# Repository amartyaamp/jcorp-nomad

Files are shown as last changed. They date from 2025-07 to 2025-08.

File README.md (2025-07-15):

# <div align="center">Jcorp Nomad</div>

<div align="center">
  Jcorp Nomad Offline Media Server
</div>

<p align="center"><b>A portable, offline media server powered by the ESP32-S3 in a thumbdrive form factor.</b><br>
Stream movies, music, books, and shows anywhere — no internet required.</p>

<p align="center">
  
  
  
</p>

---

## What is Nomad

Jcorp Nomad is an open-source offline media server built for travel, remote work, classrooms, camping, and more. It runs entirely on an ESP32-S3 dev board, creates a local Wi-Fi hotspot, and serves media through a browser-accessible interface. It does not require internet access and works similarly to in-flight entertainment systems. It also allows multiple users watching seperate media streams at the same time. 

This project is designed to be compact, simple, and easily modifiable. It includes optional 3D-printable hardware and a fully open source firmware and web interface.

---

## Project Inspiration
This project was inspired by my experience running a Jellyfin server at home. I love having full control over my media library, and Jellyfin gave me everything I wanted > streaming movies, shows, books, and music, all from my own hardware. Naturally, I started looking for ways to take that experience on the go.

My first thought was to build a portable server, but I quickly ran into some major hurdles:

- Power-hungry hardware — Even low-power x86 boxes needed a hefty battery setup to stay running for long trips.

- High cost — SBCs like the Raspberry Pi 4, plus power banks, USB storage, and screen interfaces added up quickly.

- Heat and reliability — Trying to cram a full stack of services into a compact case often led to thermal issues and instability when running software meant for server hardware.

That’s when I pivoted.

Instead of replicating a full home media server, I focused on delivering the core experience:

- Offline access

- Local Wi-Fi hotspot

- Simple media browsing and playback

- Support for multiple users

The ESP32-S3 offered just enough performance to handle all of that - with a fraction of the power draw and cost.
The result is Nomad: a minimalist, reliable, and low-cost media server that delivers the essential features of a home streaming setup in a smaller than pocket sized format.

Is it fancy? No.
Does it work? Absolutely.
And it’s open-source, so anyone can expand, improve, and adapt it for their own needs.

---

## Features

- Creates a local Wi-Fi hotspot with captive portal  
- Serves HTML media interface to any connected device  
- Streams content directly from a FAT32-formatted microSD card  
- Supports simultaneous connections (tested with up to 4 video streams)  
- No app or internet connection required  
- Open source firmware and UI  
- Customizable web interface / Features

---

## Hardware Requirements

**Disclaimer:**  
The following links are Amazon affiliate links. Purchasing through these links supports this project at no additional cost to you. Thank you for your support!

- **Waveshare ESP32-S3 Dev Board (1.47" LCD version)**  
  [https://amzn.to/4ktB6oT](https://amzn.to/4ktB6oT)

  [Backup, the other one's shiping is like 2 weeks now](https://amzn.to/4kGp7UT)

- **FAT32-formatted microSD card (16 GB minimum recommended, 64 GB preferred)**  
  [https://amzn.to/44tM1c4](https://amzn.to/44tM1c4)

- **USB power source** (e.g., battery bank or computer)

- **Optional:** 3D-printed enclosure (STL files included in the repository)

---

## Software Requirements

- Arduino IDE or PlatformIO (to flash firmware)
- Python 3.x (to run `media.py`)
- SquareLine Studio (optional, for screen UI editing)

All software used is free and available on Windows, macOS, and Linux.

---

## Quick Start

1. Flash the ESP32-S3 with the firmware in the `/firmware/` directory.
2. Format your SD card as **FAT32** and copy the web files from `/SD_Card_Template/`.
3. Place your media files into the appropriate folders (see structure below).
4. ~~Run `media.py` to generate `media.json` automatically.~~ Updated: Media.py is still there, but you dont need to run it, file will be generated on boot automaticaly!
5. Insert the SD card and power the device.
6. Connect to the Wi-Fi network named `Jcorp_Nomad`.
7. Your browser will be redirected to the offline media interface.

---

## Folder Structure (on SD Card)

```
/Movies/
    Interstellar.mp4
    Interstellar.jpg
/Shows/
    The Office/
        S01E01 - Pilot.mp4
        S01E02 - Diversity Day.mp4
    The Office.jpg
/Books/
    The Martian.pdf
    The Martian.jpg
/Music/
    track01.mp3

index.html
appleindex.html
menu.html
movies.html
shows.html
books.html
music.html
media.py
media.json
placeholder.jpg
Logo.png
favicon.ico
```
---

## Supported Formats

- Video: `.mp4`
- Audio: `.mp3`
- Books: `.pdf`
- Images: `.jpg` (used for covers and folder images only)

Ensure all images and media files use matching names for proper display.

---

## Customization

- Wi-Fi name and password can be changed in `firmware/Nomad.ino`
- Branding (logo, favicon) can be replaced in `/SD_Card_Template/`
- Sections (Movies, Music, etc.) can be removed from `menu.html`
- Web interface can be edited using any text editor
- The screen UI can be edited with SquareLine Studio (the free version is fine) 

---

## What's Included

- `/firmware/` – Arduino firmware for ESP32-S3
- `/SD_Card_Template/` – Web UI, HTML files, and `media.py`
- `/case/` – STL files for optional 3D-printed enclosure
- `/docs/` – Logos, screenshots, and design files

---

## Troubleshooting

Common issues and their solutions are detailed in the Troubleshooting section on instructibles.

Topics covered include:

- SD card read errors
- Captive portal issues on some phones
- Video playback and seeking bugs
- UI glitches or screen failure

---

## Future Plans

These are features I'd like to explore in future updates. If you'd like to contribute, feel free to fork the repo or open a pull request!

### Offline Maps with GPS Support
Inspired by [Backcountry Beacon](https://www.instructables.com/USB-Powered-Offline-Map-Server/), the goal is to serve cached map tiles and display the live GPS position from the user's phone or connected device — entirely offline.

### HTML5 Games
Similar to [Gams Offline](https://github.com/Gams-Offline/Gams), I would like to embed simple HTML5 games that work in-browser. The selection in Gams is amazing and make me think of cool math games, would be neat to have even though most require a keyboard.

### Audiobook-Friendly Mode
Improve playback for long-form audio by adding bookmarks, chapter display, and smart pause/resume. Intended for better audiobook handling in the Music section. Potentialy add an entire new audiobook section or a seperate handling system for it in books (Under read it could have a listen option).

### File Upload Over USB
Enable USB mass storage or dual-mode operation to allow users to drag and drop files directly to the SD card without removing it. This may require dynamic switching between USB and Wi-Fi server modes, or dual-core task handling. I worked on this for a long while, but couldnt find a relible way to have it switch modes and still function, usualy crashes trying to reboot media, I also wasnt able to get it to run the python script to generate media.json, a new system would be needed.

### DLNA Server Support for Tvs and VLC Media Player. 
This would give another method for acessing media on the system, Sadly softAP doesnt really let me do DLNA on the ESP32, but I am working on a solution for that. I am not sure if this is actualy possible but if I can get it working yall will know!

---

## Build Guide on Instructables

Looking for a step-by-step tutorial?  
Check out the full build guide on **Instructables** for detailed instructions, photos, and tips on setting up Jcorp Nomad.

👉 [Read the Instructables Guide](https://www.instructables.com/Jcorp-Nomad-Mini-WIFI-Media-Server/) 

---

<p align="center">
  Nomad Video Demo
  Admin Panel Demo
</p>

---

## License

This project is licensed under the [Creative Commons Attribution-NonCommercial-ShareAlike 4.0 International License](https://creativecommons.org/licenses/by-nc-sa/4.0/).

You may remix, adapt, and share this project **for non-commercial use**, as long as you give credit and share under the same terms.

For commercial licensing, please contact the author.

---

## Credits

Developed by **Jackson Studner (Jcorp Tech)**.  
Inspired by open-source offline projects like Backcountry Beacon.

If you build, remix, or improve this project, please consider submitting a pull request or tagging the project.

---

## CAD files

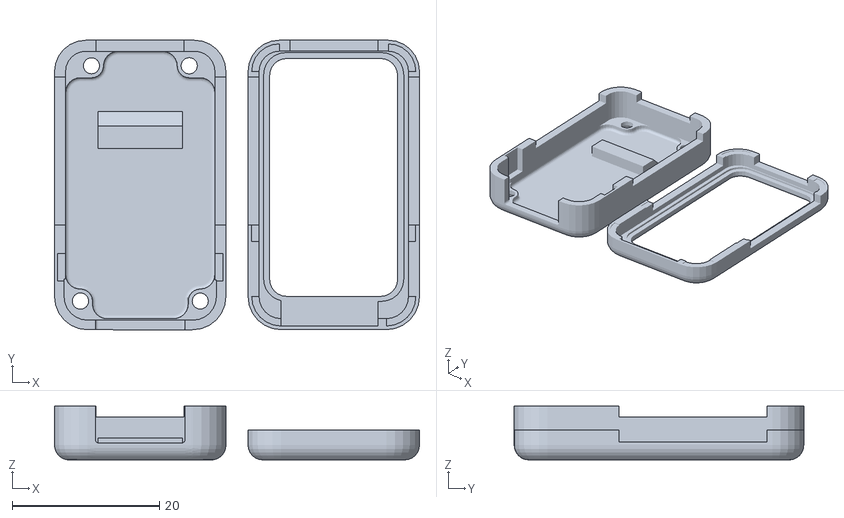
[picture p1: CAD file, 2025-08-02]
case/NomadNewCase v9.stl
49.6 x 39.4 x 7.32

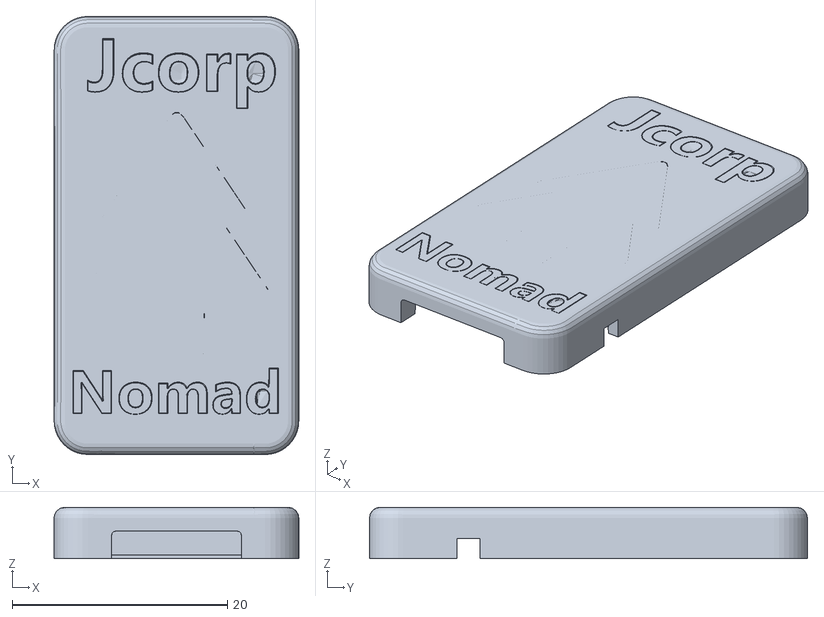
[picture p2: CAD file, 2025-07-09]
case/JcorpNomadBackCoverDuelColorMabye.stl
22.7 x 40.7 x 4.78

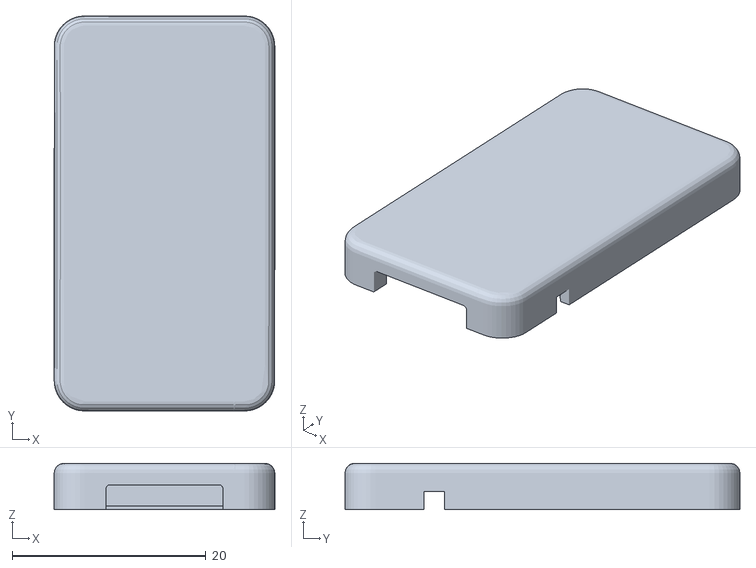
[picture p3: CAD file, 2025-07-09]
case/JcorpNomadBackCoverBLANK.stl
22.8 x 40.7 x 4.78

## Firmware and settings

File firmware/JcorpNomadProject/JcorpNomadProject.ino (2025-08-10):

// Core ESP32 + WiFi Libraries
#include "Arduino.h"
#include "WiFi.h"
#include <ESPAsyncWebServer.h>
#include "FS.h"
#include "SD_MMC.h"
#include "DNSServer.h"
#include <ArduinoJson.h>


// Waveshare Display and UI Libraries
#include "Display_ST7789.h"
#include "LVGL_Driver.h"
#include "ui.h"
#include "RGB_lamp.h"

// SPIFFS support and ESP WiFi control
#include <SPIFFS.h>
#include "esp_wifi.h"

// ==================== CONFIGURATION ====================

// WiFi network name and password (this is the hotspot the ESP32 creates)
#define WIFI_SSID "Jcorp_Nomad"
// Password MUST be at least 8 characters, must not be more than 63 characters
#define WIFI_PASSWORD "password"

// Max number of devices that can connect at once
#define MAX_CLIENTS 8

// SD card pinout for Waveshare ESP32-S3
#define SD_CLK_PIN 14
#define SD_CMD_PIN 15
#define SD_D0_PIN 16
#define SD_D1_PIN 18
#define SD_D2_PIN 17
#define SD_D3_PIN 21

// Captive portal DNS setup
const byte DNS_PORT = 53;
DNSServer dnsServer;
AsyncWebServer server(80); // Web server on port 80

int connectedClients = 0;

// Update the UI with the number of connected users
void updateUI(int userCount) {
    char buffer[10];
    snprintf(buffer, sizeof(buffer), "%d", userCount);
    lv_label_set_text(ui_uiuserlabel, buffer);
}

// Get a count of currently connected WiFi clients
void updateClientCount() {
    wifi_sta_list_t wifi_sta_list;
    if (esp_wifi_ap_get_sta_list(&wifi_sta_list) == ESP_OK) {
        connectedClients = wifi_sta_list.num;
        updateUI(connectedClients);
    }
}

void generateMediaJSON() {
    Serial.println("[MediaGen] Called generateMediaJSON()");

    if (SD_MMC.exists("/media.json")) {
        SD_MMC.remove("/media.json");
        Serial.println("[MediaGen] Old media.json removed.");
    }

    StaticJsonDocument<32768> doc;

    // Movies
    JsonArray movies = doc.createNestedArray("movies");
    File moviesDir = SD_MMC.open("/Movies");
    while (File file = moviesDir.openNextFile()) {
        if (!file.isDirectory()) {
            String name = file.name();
            if (name.endsWith(".mp4") || name.endsWith(".mkv")) {
                Serial.println("[MediaGen] Found movie: " + name);
                String base = name.substring(name.lastIndexOf('/') + 1);
                base = base.substring(0, base.lastIndexOf('.'));

                String cover = "movies/" + base + ".jpg";
                if (!SD_MMC.exists("/Movies/" + base + ".jpg")) {
                    cover = "placeholder.jpg";
                }

                JsonObject item = movies.createNestedObject();
                item["name"] = base;
                item["cover"] = cover;
                item["file"] = "Movies/" + base + name.substring(name.lastIndexOf('.'));  // Ensure full filename
            }
        }
    }

    // Shows
    JsonArray shows = doc.createNestedArray("shows");
    File showsRoot = SD_MMC.open("/Shows");

    while (File folder = showsRoot.openNextFile()) {
        if (folder.isDirectory()) {
            String folderName = String(folder.name()); // just "GravityFalls"
            String fullPath = "/Shows/" + folderName;

            Serial.println("[MediaGen] Found show folder: " + folderName);

            JsonObject show = shows.createNestedObject();
            show["name"] = folderName;

            String coverPath = "shows/" + folderName + ".jpg";
            if (!SD_MMC.exists("/Shows/" + folderName + ".jpg")) {
                coverPath = "placeholder.jpg";
            }
            show["cover"] = coverPath;

            JsonArray episodes = show.createNestedArray("episodes");

            File epFolder = SD_MMC.open(fullPath);
            while (File ep = epFolder.openNextFile()) {
                if (!ep.isDirectory()) {
                    String epName = String(ep.name());
                    if (epName.endsWith(".mp4") || epName.endsWith(".mkv")) {
                        String epBase = epName.substring(epName.lastIndexOf('/') + 1);

                        JsonObject epItem = episodes.createNestedObject();
                        epItem["name"] = epBase;
                        epItem["file"] = "Shows/" + folderName + "/" + epBase;

                        Serial.println("  [MediaGen] Episode: " + epBase);
                    }
                }
            }
        }
    }




    // Books
    JsonArray books = doc.createNestedArray("books");
    File booksDir = SD_MMC.open("/Books");
    while (File file = booksDir.openNextFile()) {
        if (!file.isDirectory()) {
            String name = file.name();
            if (name.endsWith(".pdf") || name.endsWith(".epub")) {
                Serial.println("[MediaGen] Found book: " + name);
                String base = name.substring(name.lastIndexOf('/') + 1);
                base = base.substring(0, base.lastIndexOf('.'));

                String cover = "books/" + base + ".jpg";
                if (!SD_MMC.exists("/Books/" + base + ".jpg")) {
                    cover = "placeholder.jpg";
                }

                JsonObject item = books.createNestedObject();
                item["name"] = base;
                item["cover"] = cover;
                item["file"] = "Books/" + base + name.substring(name.lastIndexOf('.'));
            }
        }
    }

    // Music
    JsonArray music = doc.createNestedArray("music");
    File musicDir = SD_MMC.open("/Music");
    while (File file = musicDir.openNextFile()) {
        if (!file.isDirectory()) {
            String name = file.name();
            if (name.endsWith(".mp3")) {
                Serial.println("[MediaGen] Found music: " + name);
                String base = name.substring(name.lastIndexOf('/') + 1);
                base = base.substring(0, base.lastIndexOf('.'));

                String cover = "music/" + base + ".jpg";
                if (!SD_MMC.exists("/Music/" + base + ".jpg")) {
                    cover = "placeholder.jpg";
                }

                JsonObject item = music.createNestedObject();
                item["name"] = base;
                item["cover"] = cover;
                item["file"] = "Music/" + base + ".mp3";
            }
        }
    }

    // Save to media.json
    File jsonFile = SD_MMC.open("/media.json", FILE_WRITE);
    if (!jsonFile) {
        Serial.println("[MediaGen] Error opening media.json for writing.");
        return;
    }

    serializeJsonPretty(doc, jsonFile);
    jsonFile.close();
    Serial.println("[MediaGen] media.json created successfully.");
}


// ==================== MEDIA STREAM HANDLER ====================

// Handles video/audio streaming via range requests
void handleRangeRequest(AsyncWebServerRequest *request) {
    if (!request->hasParam("file")) {
        request->send(400, "text/plain", "File parameter missing");
        return;
    }

    String filePath = request->getParam("file")->value();
    if (!SD_MMC.exists(filePath)) {
        request->send(404, "text/plain", "File not found");
        return;
    }

    File file = SD_MMC.open(filePath, "r");
    size_t fileSize = file.size();

    Serial.println("=== Range Request Debug ===");
    Serial.println("File requested: " + filePath);
    Serial.println("File size: " + String(fileSize));

    if (request->method() == HTTP_HEAD) {
        Serial.println("HEAD request received");
        AsyncWebServerResponse *headResponse = request->beginResponse(200, "application/octet-stream", "");
        headResponse->addHeader("Content-Length", String(fileSize));
        request->send(headResponse);
        file.close();
        return;
    }

    // Handle "Range" header to support seeking and chunked media playback
    String rangeHeader = request->header("Range");
    Serial.println("Raw Range header: " + rangeHeader);

    size_t startByte = 0, endByte = fileSize - 1;
    if (rangeHeader.startsWith("bytes=")) {
        int dashIndex = rangeHeader.indexOf('-');
        startByte = rangeHeader.substring(6, dashIndex).toInt();
        if (dashIndex + 1 < rangeHeader.length()) {
            endByte = rangeHeader.substring(dashIndex + 1).toInt();
        }
    }
    if (endByte >= fileSize) endByte = fileSize - 1;
    size_t contentLength = endByte - startByte + 1;

    Serial.println("Computed startByte: " + String(startByte));
    Serial.println("Computed endByte: " + String(endByte));
    Serial.println("Content length: " + String(contentLength));
    Serial.println("============================");

    AsyncWebServerResponse *response = request->beginResponse("video/mp4", contentLength,
        [file, startByte, endByte, contentLength](uint8_t *buffer, size_t maxLen, size_t index) mutable -> size_t {
            file.seek(startByte + index);
            size_t bytesToRead = min(maxLen, endByte - (startByte + index) + 1);
            size_t bytesRead = file.read(buffer, bytesToRead);
            if (index + bytesRead >= contentLength) {
                file.close();
            }
            return bytesRead;
        }
    );

    response->addHeader("Content-Type", "video/mp4");
    response->addHeader("Accept-Ranges", "bytes");
    response->addHeader("Content-Range", "bytes " + String(startByte) + "-" + String(endByte) + "/" + String(fileSize));
    response->addHeader("Cache-Control", "no-cache");
    response->addHeader("Pragma", "no-cache");
    response->setCode(206); // Partial Content
    request->send(response);
}

// ==================== SETUP ====================

void setup() {
    LCD_Init();
    Lvgl_Init();
    Set_Backlight(90); // Set display brightness
    ui_init();         // Load the GUI

    Serial.begin(115200);
    delay(1000);
    Serial.println("\n=== ESP32-S3 Captive Portal & SDMMC Server ===");

    // Start WiFi Access Point
    WiFi.softAP(WIFI_SSID, WIFI_PASSWORD);
    Serial.println("WiFi AP started...");

    // Initialize SD card
    Serial.println("Initializing SD Card...");
    if (!SD_MMC.setPins(SD_CLK_PIN, SD_CMD_PIN, SD_D0_PIN, SD_D1_PIN, SD_D2_PIN, SD_D3_PIN)) {
        Serial.println("ERROR: SDMMC Pin configuration failed!");
        return;
    }
    if (!SD_MMC.begin("/sdcard", true)) {
        Serial.println("ERROR: SDMMC Card initialization failed.");
        return;
    }
    Serial.println("SD Card initialized successfully!");

    delay(2000); 

    generateMediaJSON();  

    // Start Captive DNS redirection
    dnsServer.start(DNS_PORT, "*", WiFi.softAPIP());

    // Captive Portal: Redirect all unknown requests
    server.onNotFound([](AsyncWebServerRequest *request) {
        if (request->hasHeader("User-Agent")) {
            String userAgent = request->header("User-Agent");
            Serial.println("User-Agent: " + userAgent);

            if (userAgent.indexOf("iPhone") >= 0 || userAgent.indexOf("iPad") >= 0 || userAgent.indexOf("Macintosh") >= 0) {
                Serial.println("Apple device detected. Serving appleindex.html");
                request->send(SD_MMC, "/appleindex.html", "text/html");
                return;
            }
        }
        Serial.println("Non-Apple device. Serving index.html");
        request->send(SD_MMC, "/index.html", "text/html");
    });

    // Captive triggers for Apple & Android devices
    server.on("/hotspot-detect.html", HTTP_GET, [](AsyncWebServerRequest *request) {
        Serial.println("Apple captive portal request detected, serving appleindex.html");
        request->send(SD_MMC, "/appleindex.html", "text/html");
    });

    server.on("/generate_204", HTTP_GET, [](AsyncWebServerRequest *request) {
        Serial.println("Android/NORMAL captive portal request detected, serving index.html");
        request->send(SD_MMC, "/index.html", "text/html");
    });
    server.on("/dlna/desc.xml", HTTP_GET, [](AsyncWebServerRequest *request){
      request->send(200, "text/xml", R"rawliteral(
        <?xml version="1.0"?>
        <root xmlns="urn:schemas-upnp-org:device-1-0">
          <specVersion>
            <major>1</major>
            <minor>0</minor>
          </specVersion>
          <device>
            <deviceType>urn:schemas-upnp-org:device:MediaServer:1</deviceType>
            <friendlyName>Nomad Media Server</friendlyName>
            <manufacturer>JCorp</manufacturer>
            <modelName>Nomad</modelName>
            <UDN>uuid:ESP32-DLNA-FAKE-1234</UDN>
          </device>
        </root>
      )rawliteral");
    });

    server.on("/dlna/contentdir.xml", HTTP_GET, [](AsyncWebServerRequest *request){
      String xml = "<?xml version=\"1.0\"?><ContentDirectory>";
      File root = SD_MMC.open("/Movies");
      if (root && root.isDirectory()) {
        File file = root.openNextFile();
        while (file) {
          if (!file.isDirectory()) {
            String name = file.name();
            xml += "<item>";
            xml += "<title>" + name + "</title>";
            xml += "<res protocolInfo=\"http-get:*:video/mp4:*\">";
            xml += "http://192.168.4.1/Movies/" + name + "</res>";
            xml += "</item>";
          }
          file = root.openNextFile();
        }
      }
      xml += "</ContentDirectory>";
      request->send(200, "text/xml", xml);
    });


    // Static HTML routes
    server.serveStatic("/movies.html", SD_MMC, "/movies.html");
    server.serveStatic("/music.html", SD_MMC, "/music.html");
    server.serveStatic("/books.html", SD_MMC, "/books.html");
    server.serveStatic("/shows.html", SD_MMC, "/shows.html");

    // Serve root directory and default to index.html
    server.serveStatic("/", SD_MMC, "/").setDefaultFile("index.html");

    // Endpoint for video/audio streaming
    server.on("/media", HTTP_GET, handleRangeRequest);

    // Start the web server
    server.begin();
    Serial.println("Web Server started!");
}

// ==================== MAIN LOOP ====================

void loop() {
    dnsServer.processNextRequest(); // Keeps captive DNS alive
    Timer_Loop();                   // Handles UI timing events
    RGB_Lamp_Loop(2);               // Optional LED effect loop
    delay(5);                       // Slight delay

    updateClientCount();           // Refresh user count
}

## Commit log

2025-07-09 Blank Version of the Nomad Back Cover
    Sleek look without the branding, or use this as a base to emboss your own branding!
    [JcorpNomadBackCoverBLANK.stl]
2025-07-09 Back Cover filled in branding, Duel Color print?
    Never printed duel color before, I run old first gen enders. That being said this file might work for your duel color needs!
    [JcorpNomadBackCoverDuelColorMabye.stl]
2025-08-02 Add files via upload
    Prototype cover for retail, going to do tri color 3d printing maybe? that or getting the injection molder working (which would be sick). For now this version has screw holes, and requires 4x m2x4 scr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
    [NomadNewCase v9.stl]
2025-08-10 Add GitHub Actions workflow for building ESP32-S3 firmware
2025-08-10 Add ArduinoJson library installation to GitHub Actions workflow
2025-08-10 Specify version 3.5.0 for ESP32 core installation in GitHub Actions workflow
2025-08-10 Remove specific version for ESP32 core installation and update ESPAsyncWebServer library version in GitHub Actions workflow
2025-08-10 Update ESP32 core version to 3.5.0 and upgrade ESPAsyncWebServer library to 3.7.4 in GitHub Actions workflow
2025-08-10 Remove specific version for ESP32 core installation in GitHub Actions workflow
2025-08-10 Specify versions for ESP32 core and ESPAsyncWebServer libraries in GitHub Actions workflow
2025-08-10 Add library path to Arduino CLI compile command in GitHub Actions workflow
2025-08-10 Change include directive for ESPAsyncWebServer library to angle brackets
2025-08-10 Update Arduino CLI compile command with additional options and fix typo in libraries flag
2025-08-10 Fix typo in libraries flag in Arduino CLI compile command
2025-08-10 Fix fqbn flag in Arduino CLI compile command for ESP32
2025-08-10 Update Arduino CLI compile command to include build properties and fix fqbn flag
2025-08-10 Update Arduino CLI compile command with custom build properties and add partition file
    [custom_16MB.csv]
2025-08-10 Refactor Arduino CLI compile command to improve readability and maintainability
2025-08-11 install arduino

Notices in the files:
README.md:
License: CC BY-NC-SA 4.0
